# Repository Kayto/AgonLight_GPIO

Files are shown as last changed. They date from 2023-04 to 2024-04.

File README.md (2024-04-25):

# AgonLight_GPIO

## Background
Agon Light is a compact low-cost board that is both a microcomputer and a BASIC-programmed microcontroller. It is intended to be easily hackable and allow interfacing with the outside world. It features 20x GPIO, plus SPI, I2C, UART for serial communication and allows a great opportunity for learning and experimentation.

## Introduction 

This repo is intended to provide some simple add on boards for gpio examples and experiments. Although I am of the 8 bit vintage, I consider myself a novice. I enjoy hardware making as a way to better understand the inner hardware workings and to ultimately improve my coding. All is a work in progress and is open to contributions and ideas, within the stated aims and limitations of this project.

## Aims
* Provide a range of simple IO hardware to aid coding in BBC BASIC.
* To be useful in gaining a general understanding of GPIO usage and real world interfacing.
* Stick to the general GPIOs only.
* Avoid cables and breadboards and try to fit a standardised form factor. In this case a plugable "faceplate" for the exiting gpio port. The board should avoid constraining any existing ports and access.
* Ideally, provide onboard visual feedback to aid learning.
* Avoid additional hardware processing on the add on board. Keeping access to the low level hardware prevents adding more complications when learning. I.e. GALs, additional controller ICs are to be avoided.

## The PCBs

KiCad, Schematics and Gerbers are provided. Renders of the boards are shown in the KiCad directory. Please review before making a commitment. No warranties or support are provided. As of this date PCBs are not yet tested but I will mark as such once done.

#### #1 - The Blinkenlight. - tested working
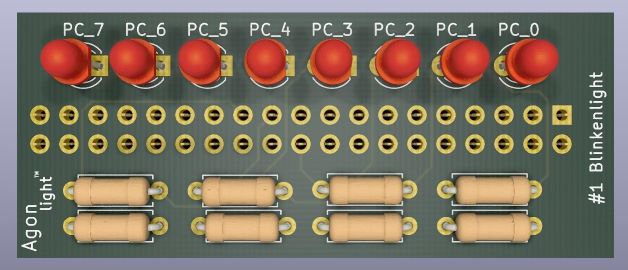
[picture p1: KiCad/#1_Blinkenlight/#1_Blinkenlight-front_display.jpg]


Every 8 bit computer needs blinky lights. Not only do they look like good, they are useful for debugging and understanding what is going on at a bit level.
The Blinkenlight PCB is pretty much the breadboard example from the official documentation but without the fiddly wires. It directly plugs into the GPIO header and provides an easily viewable "faceplate". This presents the form for future boards.

#### #2 - 7 segment display. - tested working
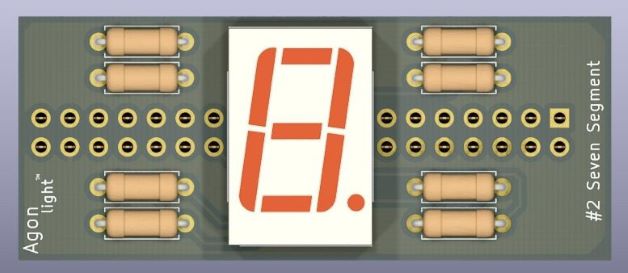
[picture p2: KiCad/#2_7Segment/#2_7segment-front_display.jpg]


This is a single 7 segment display linked to the Port C GPIOs. Allows a simple message display with a delay. Ok its only single digits but something to build on.
A caution on this is that you need a 7 segment display to suit the pin out (they do vary). Review the schematics, Pin 3 and 8 are power.I have provided a solder jumper for setting of common anode and common cathode displays. Note that for common anode the coding assumes a LOW signal for on and HIGH for off.

#### #3 - Double Seven
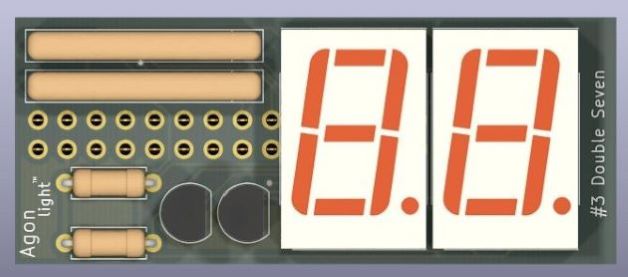
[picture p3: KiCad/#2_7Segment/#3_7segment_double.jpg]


**In progress.**

This is a **double** 7 segment display linked to the Port C GPIOs for data and 2No. Port D GPIOs to do the multiplexing.
To save space resistor networks are used instead of individual resistors.

#### #4 - Moody. - tested working
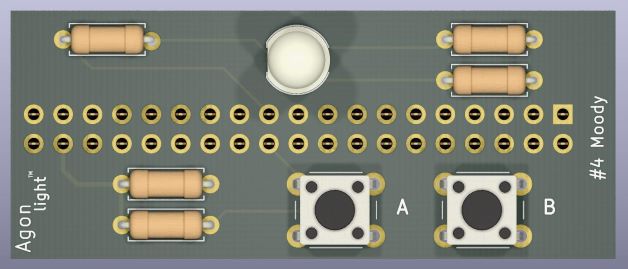
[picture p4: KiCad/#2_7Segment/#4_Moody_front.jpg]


This is an RGB LED linked to the Port C GPIOs, 2No. push buttons are also provided. The two push buttons on PC_3 and PC_4 are to establish some input and mode switching capability. 

## The Code

I have created some code to introduce the boards. As said, coding is not my strength so excuse the code, in some cases its not a great example but enough to get things going and for a challenge to improve.
To view the code add the .BBC files to the SD card and load via BBC BASIC then type LIST.

| Board | Code | Description |
|:---|:---|:-----|
|[#1_Blinkenlight](https://github.com/Kayto/AgonLight_GPIO/tree/main/KiCad/%231_Blinkenlight) | [PortC_blink.bbc](https://github.com/Kayto/AgonLight_GPIO/tree/main/Code) | select individual LEDs, set number of blinks and speed. |
|[#1_Blinkenlight](https://github.com/Kayto/AgonLight_GPIO/tree/main/KiCad/%231_Blinkenlight) | [gpioknight.bbc](https://github.com/Kayto/AgonLight_GPIO/tree/main/Code)| Some blinky patterns. Excuse the code, its a bad example with lots of inefficient duplication to get things done. The **challenge** is open to simplify this, perhaps a data array for the gpio commands and a single procedure for the delay?|
|[#1_Blinkenlight](https://github.com/Kayto/AgonLight_GPIO/tree/main/KiCad/%231_Blinkenlight) | [random8blink.bbc](https://github.com/Kayto/AgonLight_GPIO/tree/main/Code)| An easy change to PortC-Blink, uses the random function and fixed blink speed to just randomly blink the 8 LEDs!|
|[#2_seven_segment](https://github.com/Kayto/AgonLight_GPIO/tree/main/KiCad/%232_7Segment)|  [diceroll.bbc](https://github.com/Kayto/AgonLight_GPIO/tree/main/Code) | A random 1-6 generator for board games, handy. | 
|[#2_seven_segment](https://github.com/Kayto/AgonLight_GPIO/tree/main/KiCad/%232_7Segment)|  [counter.bbc](https://github.com/Kayto/AgonLight_GPIO/tree/main/Code) | A single digit counter, you're welcome. | 
|[#4_Moody](https://github.com/Kayto/AgonLight_GPIO/tree/main/KiCad/%234_Moody)|  [moodyfade.bbc](https://github.com/Kayto/AgonLight_GPIO/tree/main/Code) | An RGB fade using some crude PWM in BBC BASIC. | 
|[#4_Moody](https://github.com/Kayto/AgonLight_GPIO/tree/main/KiCad/%234_Moody)|  [moodybutton.bbc](https://github.com/Kayto/AgonLight_GPIO/tree/main/Code) | The RGB fade but now includes buttons. Button A for on and off. Button B to increase the fade speed.| 

## Disclaimer & Credits

Just a note that I am not in any way affiliated or linked with the Agon project.
I am just an aspiring maker, sharing hobbyist builds.
Thanks to the Agon project and supporters.

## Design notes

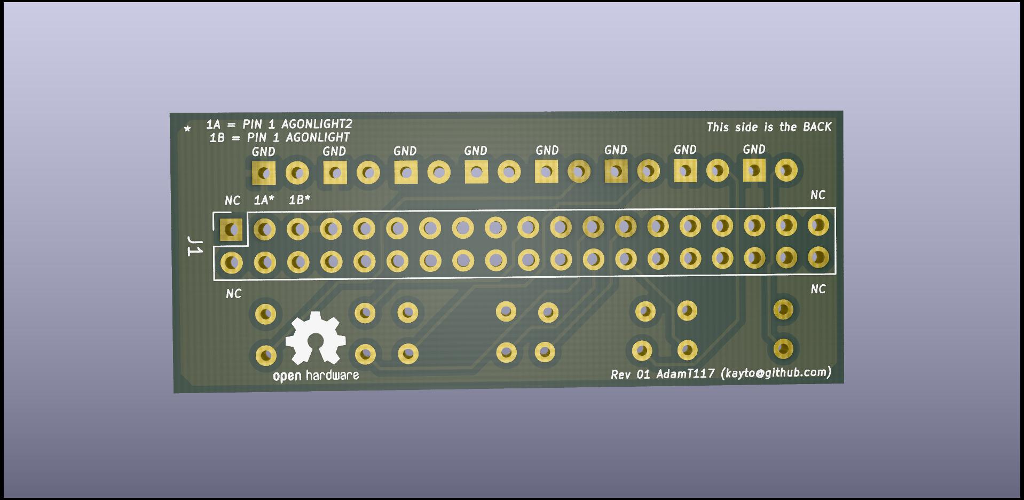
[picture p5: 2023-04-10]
KiCad/#1_Blinkenlight/#1_Blinkenlight-backPCB.jpg

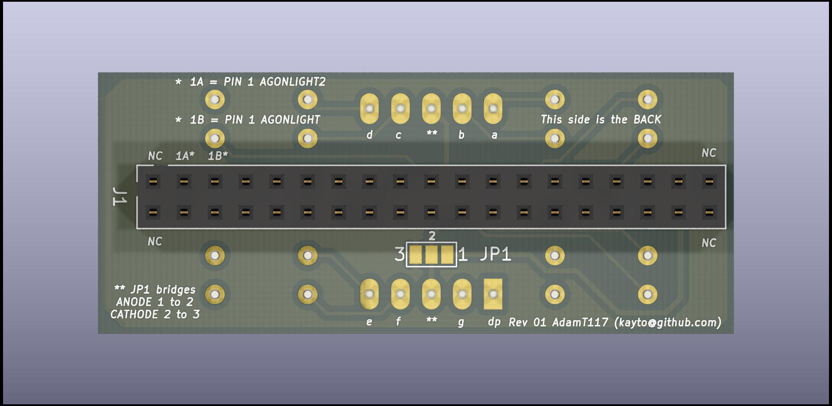
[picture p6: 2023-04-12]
KiCad/#2_7Segment/#2_7segment-back.jpg

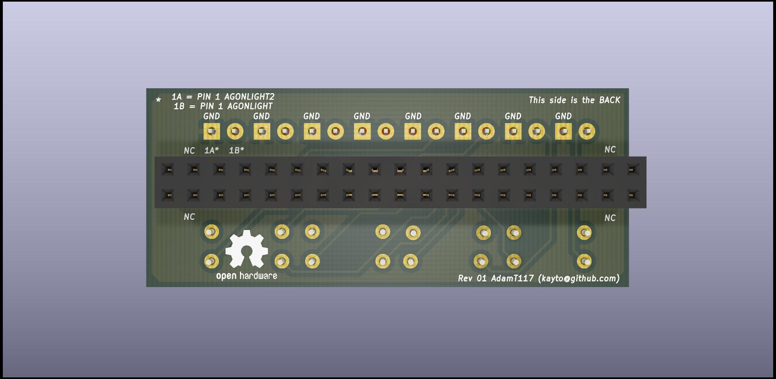
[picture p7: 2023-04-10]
KiCad/#1_Blinkenlight/#1_Blinkenlight-back.jpg

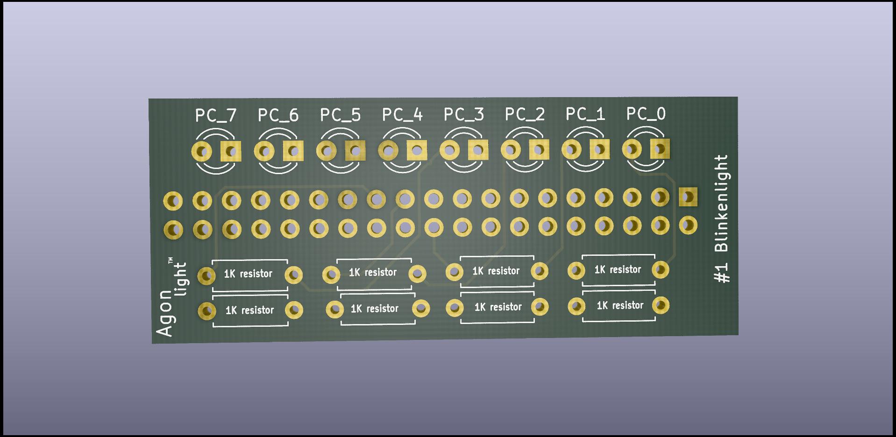
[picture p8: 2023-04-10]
KiCad/#1_Blinkenlight/#1_Blinkenlight-frontPCB.jpg

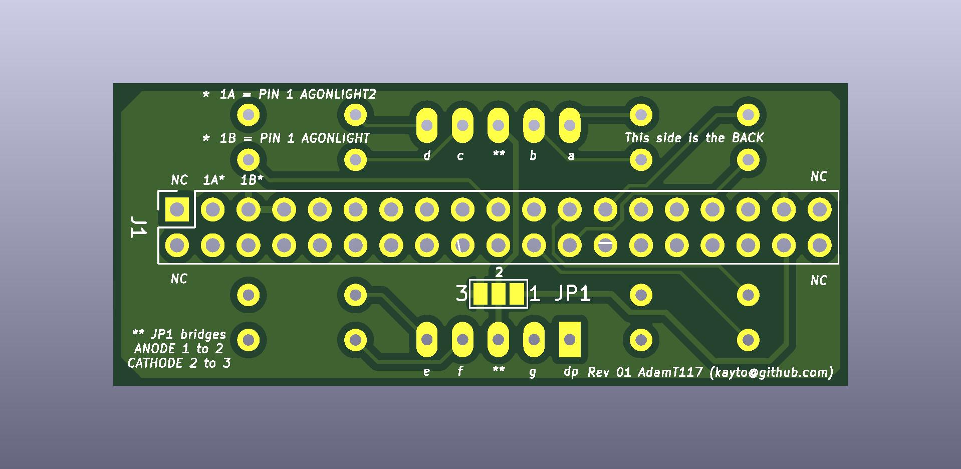
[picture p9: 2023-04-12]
KiCad/#2_7Segment/#2_7segment-back-PCB.jpg

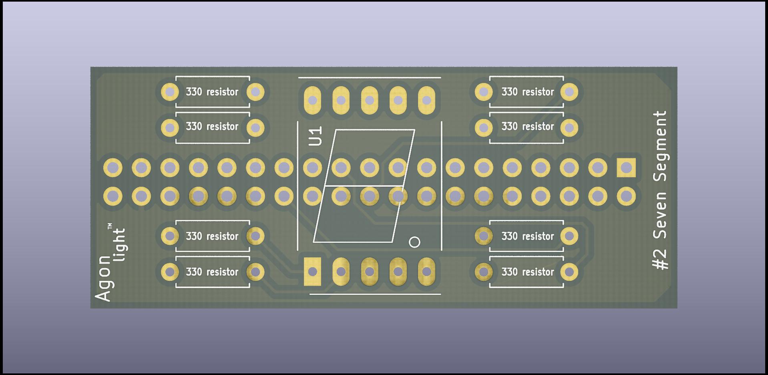
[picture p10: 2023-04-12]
KiCad/#2_7Segment/#2_7segment-front-PCB.jpg

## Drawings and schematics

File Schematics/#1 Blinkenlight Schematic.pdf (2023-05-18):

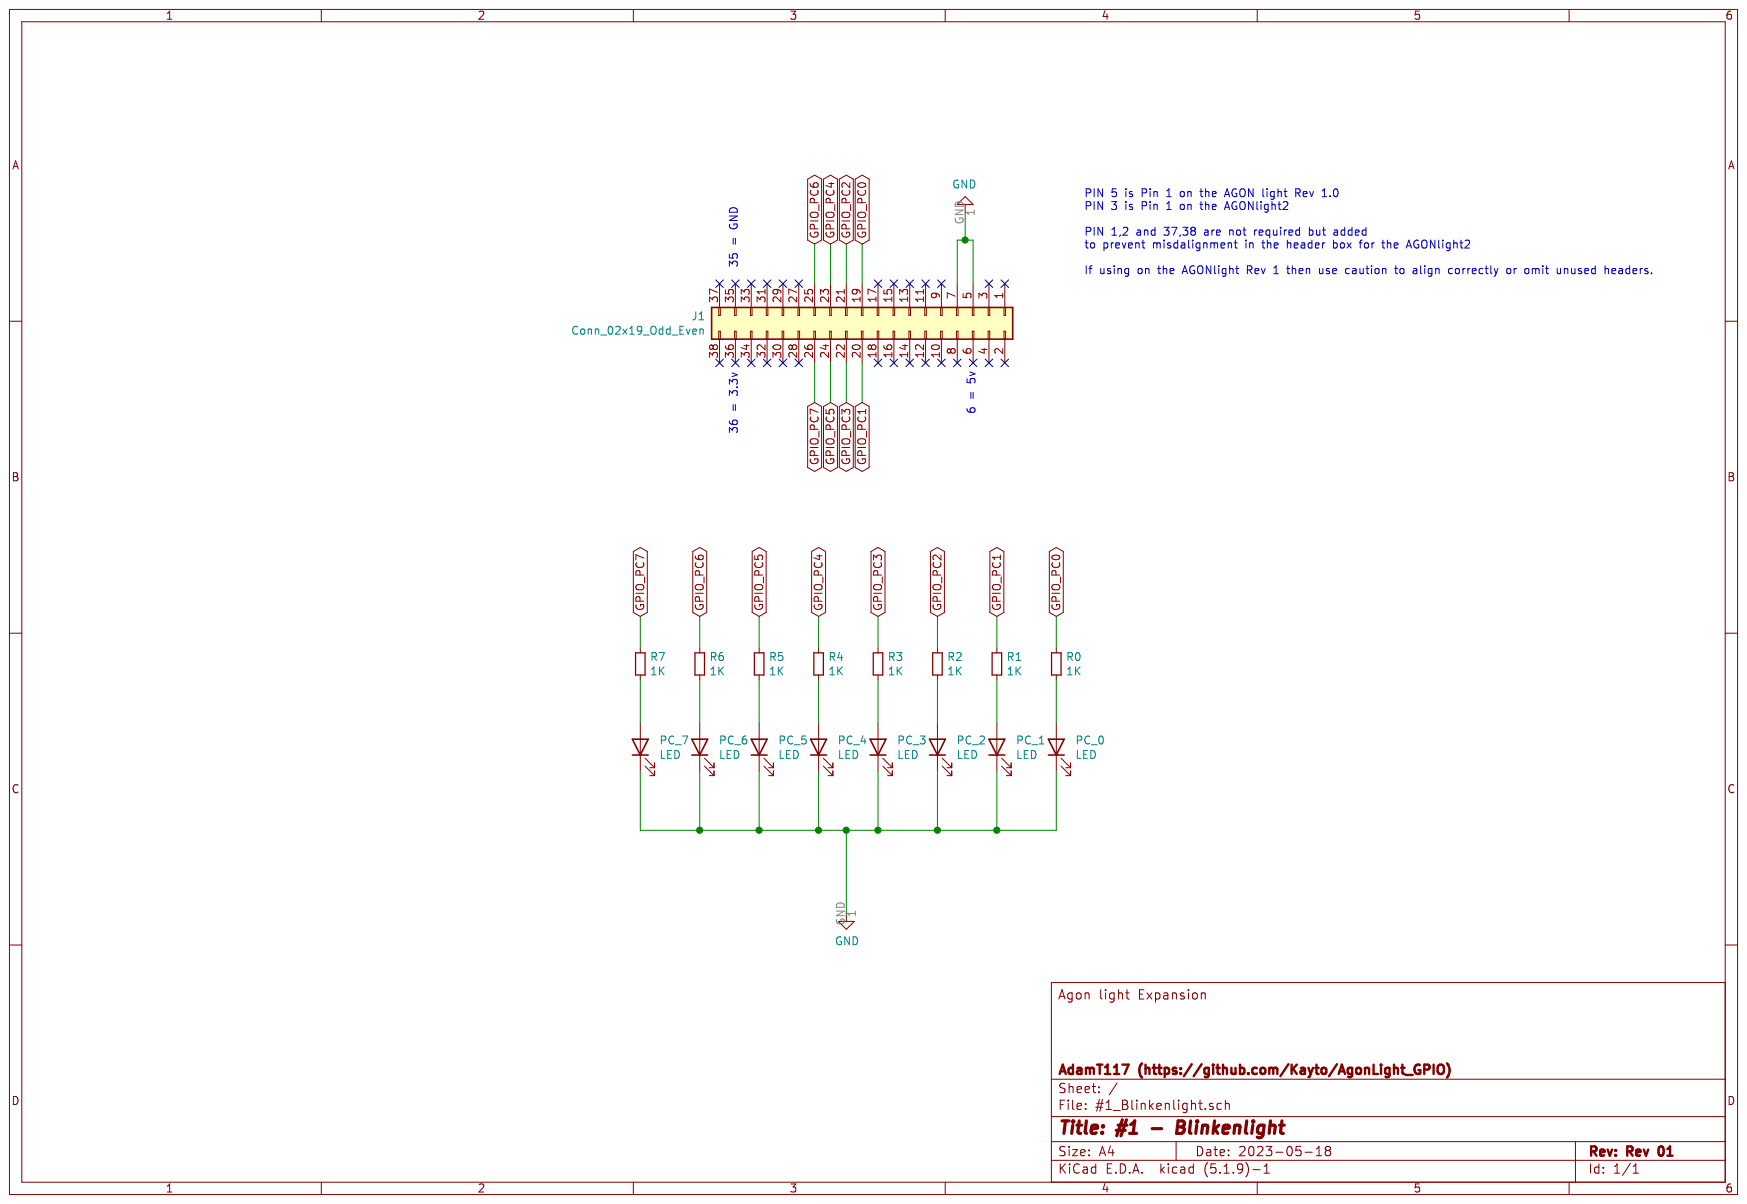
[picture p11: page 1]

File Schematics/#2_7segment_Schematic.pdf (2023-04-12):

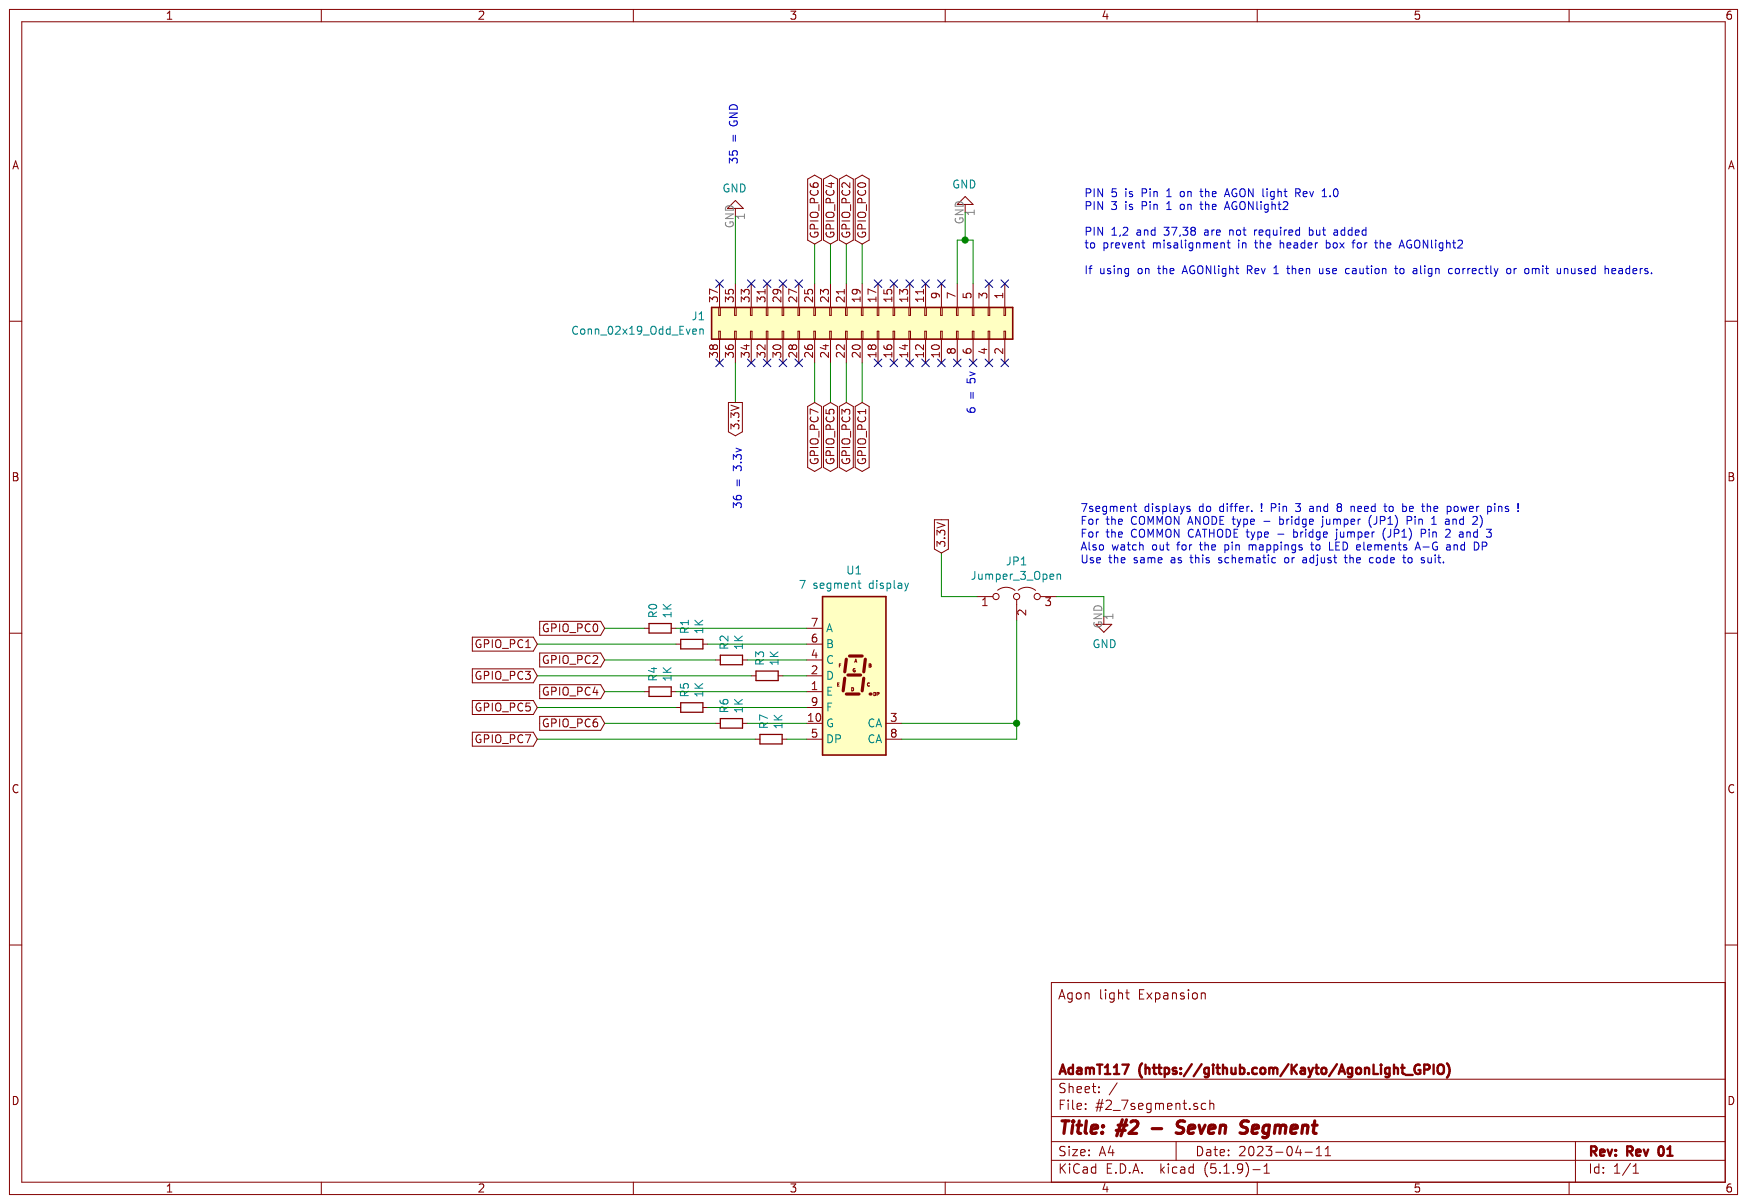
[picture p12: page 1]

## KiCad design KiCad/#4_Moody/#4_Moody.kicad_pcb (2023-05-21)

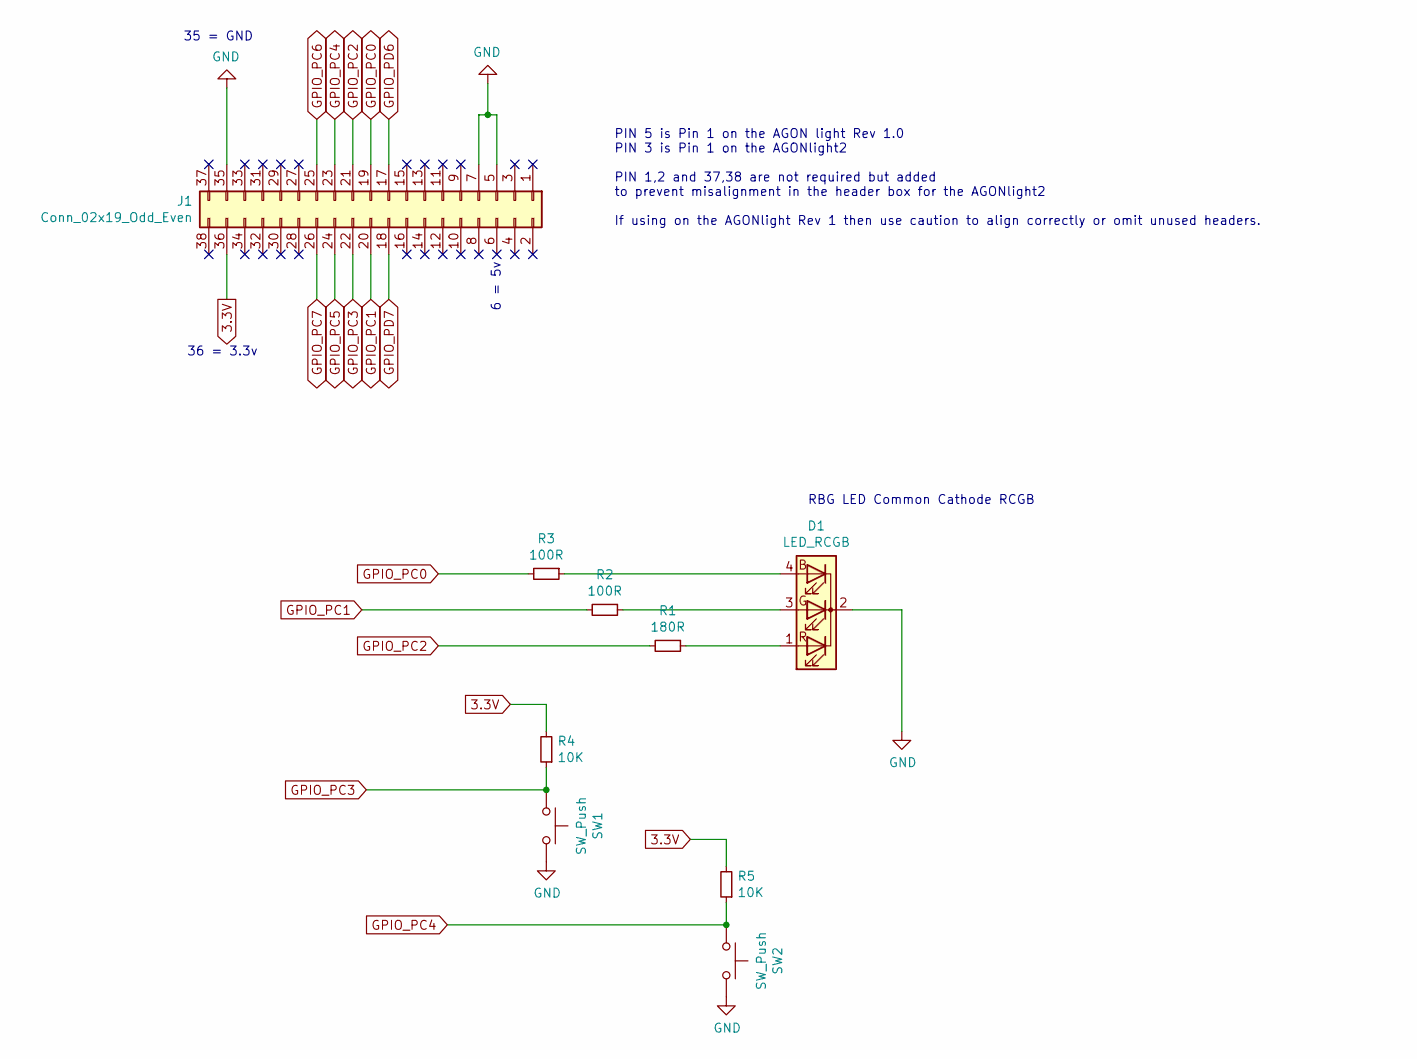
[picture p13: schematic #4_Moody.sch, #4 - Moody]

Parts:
D1: LED_RCGB; LED_D5.0mm-4_RGB
J1: Conn_02x19_Odd_Even; PinSocket_2x19_P2.54mm_Vertical
R1: 180R; R_Axial_DIN0207_L6.3mm_D2.5mm_P7.62mm_Horizontal
R2, R3: 100R; R_Axial_DIN0207_L6.3mm_D2.5mm_P7.62mm_Horizontal
R4, R5: 10K; R_Axial_DIN0207_L6.3mm_D2.5mm_P7.62mm_Horizontal
SW1, SW2: SW_Push; SW_PUSH_6mm_H4.3mm

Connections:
3.3V: J1.36, R4.2, R5.2
GND: D1.2 (K), J1.5, J1.7, J1.35, SW1.2, SW2.2
GPIO_PC0: J1.19, R3.2
GPIO_PC1: J1.20, R2.2
GPIO_PC2: J1.21, R1.2
GPIO_PC3: J1.22, R4.1, SW1.1
GPIO_PC4: J1.23, R5.1, SW2.1
GPIO_PC5: J1.24
GPIO_PC6: J1.25
GPIO_PC7: J1.26
GPIO_PD6: J1.17
GPIO_PD7: J1.18
unnamed: D1.1 (RA), R1.1
unnamed: D1.3 (GA), R2.1
unnamed: D1.4 (BA), R3.1

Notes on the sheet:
PIN 5 is Pin 1 on the AGON light Rev 1.0 PIN 3 is Pin 1 on the AGONlight2 PIN 1,2 and 37,38 are not required but added to prevent misalignment in the header box for the AGONlight2 If using on the AGONlight Rev 1 then use caution to align correctly or omit unused headers.
35 = GND
36 = 3.3v
6 = 5v
RBG LED Common Cathode RCGB

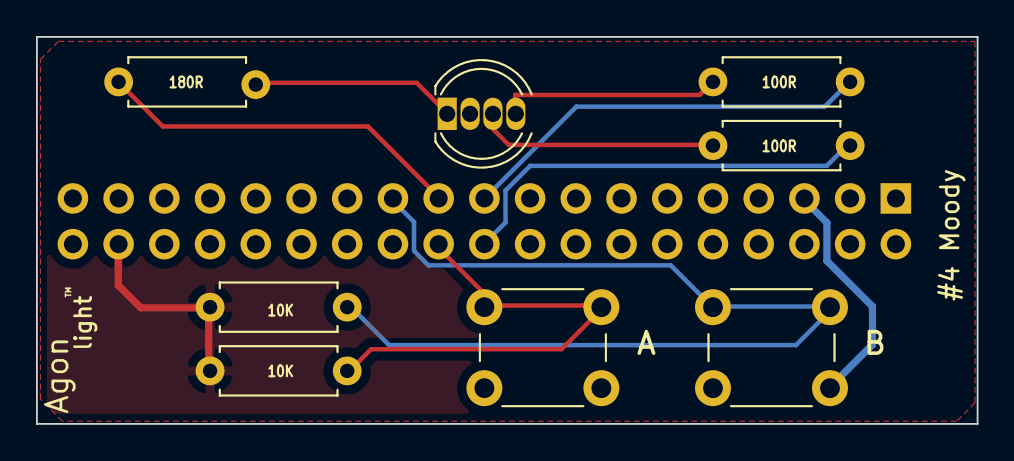
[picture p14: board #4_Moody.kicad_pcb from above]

Board: 2 copper layers, 52.3 x 21.5 mm, 9 parts (1 on the bottom side), 10 nets.

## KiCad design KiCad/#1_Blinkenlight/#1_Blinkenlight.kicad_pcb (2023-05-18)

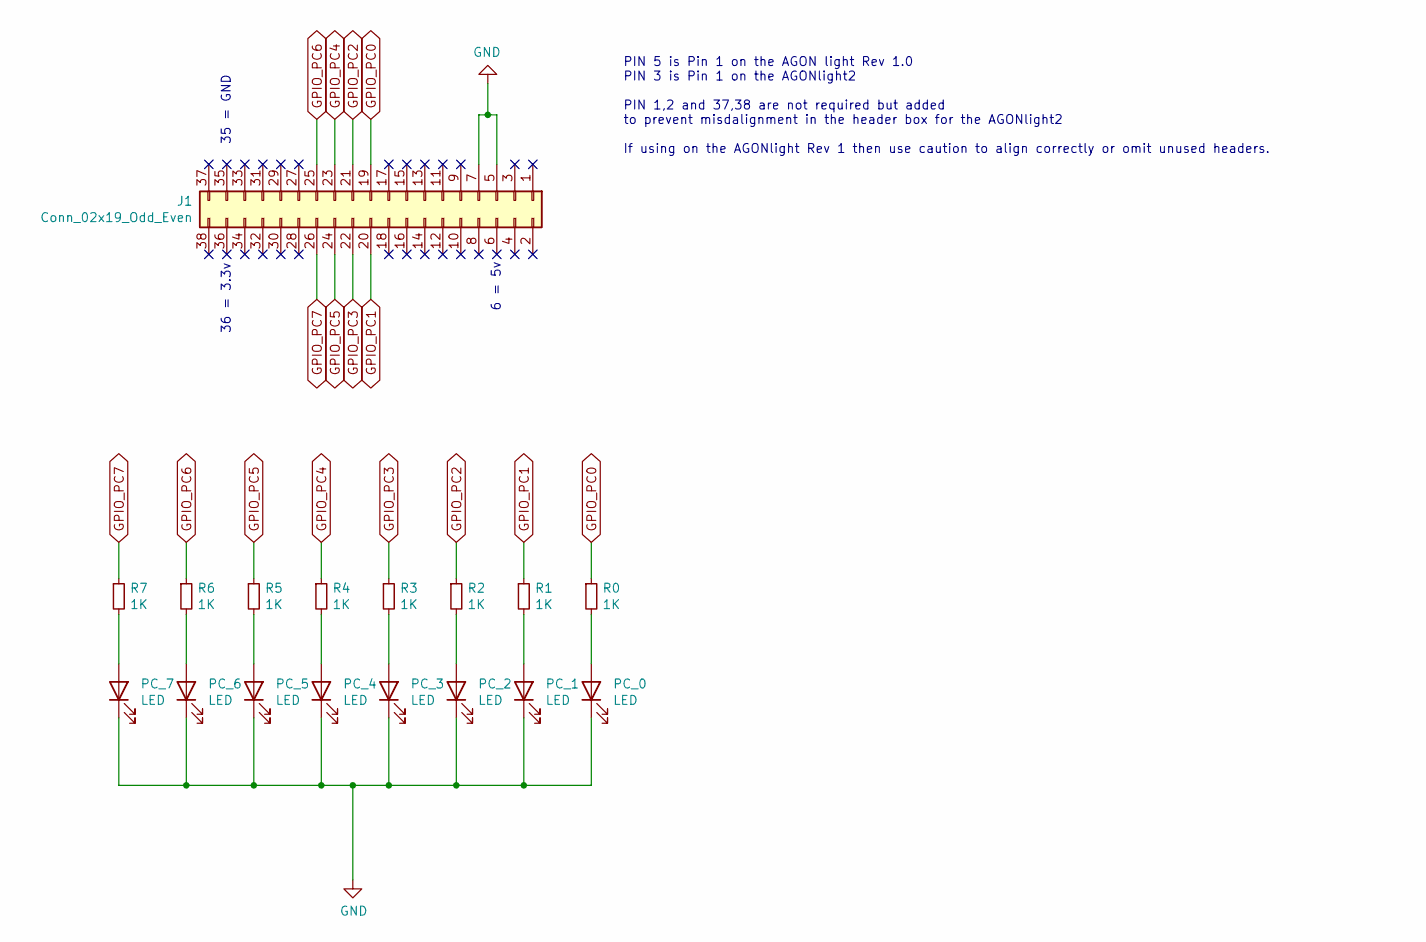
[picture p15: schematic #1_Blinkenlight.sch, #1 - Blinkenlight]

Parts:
J1: Conn_02x19_Odd_Even; PinSocket_2x19_P2.54mm_Vertical
PC_0, PC_1, PC_2, PC_3, PC_4, PC_5, PC_6, PC_7: LED; LED_D3.0mm
R0, R1, R2, R3, R4, R5, R6, R7: 1K; R_Axial_DIN0207_L6.3mm_D2.5mm_P7.62mm_Horizontal

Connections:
GND: J1.5, J1.7, PC_0.1 (K), PC_1.1 (K), PC_2.1 (K), PC_3.1 (K), PC_4.1 (K), PC_5.1 (K), PC_6.1 (K), PC_7.1 (K)
GPIO_PC0: J1.19, R0.1
GPIO_PC1: J1.20, R1.1
GPIO_PC2: J1.21, R2.1
GPIO_PC3: J1.22, R3.1
GPIO_PC4: J1.23, R4.1
GPIO_PC5: J1.24, R5.1
GPIO_PC6: J1.25, R6.1
GPIO_PC7: J1.26, R7.1
unnamed: PC_0.2 (A), R0.2
unnamed: PC_1.2 (A), R1.2
unnamed: PC_2.2 (A), R2.2
unnamed: PC_3.2 (A), R3.2
unnamed: PC_4.2 (A), R4.2
unnamed: PC_5.2 (A), R5.2
unnamed: PC_6.2 (A), R6.2
unnamed: PC_7.2 (A), R7.2

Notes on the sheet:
PIN 5 is Pin 1 on the AGON light Rev 1.0 PIN 3 is Pin 1 on the AGONlight2 PIN 1,2 and 37,38 are not required but added to prevent misdalignment in the header box for the AGONlight2 If using on the AGONlight Rev 1 then use caution to align correctly or omit unused headers.
35 = GND
36 = 3.3v
6 = 5v

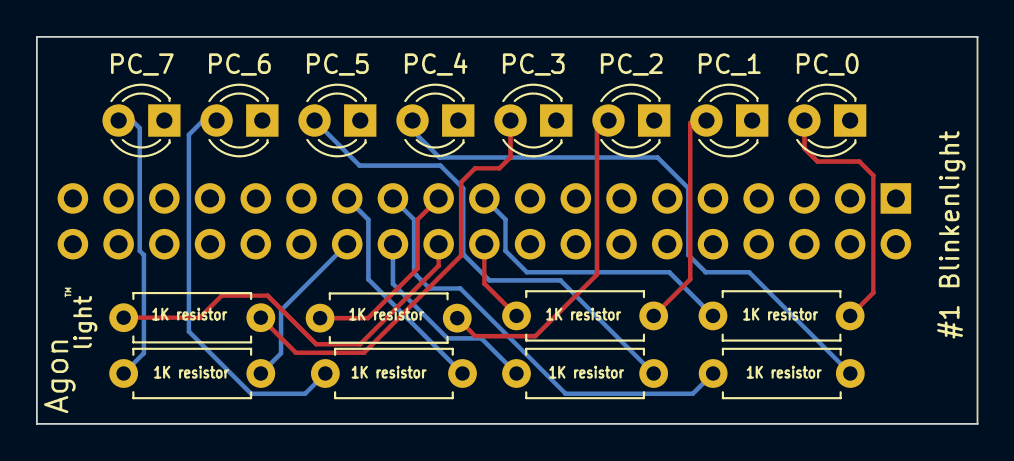
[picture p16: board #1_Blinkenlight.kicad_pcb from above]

Board: 2 copper layers, 52.3 x 21.5 mm, 17 parts (1 on the bottom side), 17 nets.

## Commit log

2023-04-10 KiCad and Gerbers added
    [#1_Blinkenlight-B_Cu.gbl, #1_Blinkenlight-B_Mask.gbs, #1_Blinkenlight-B_Paste.gbp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]
2023-04-12 #2 7 segment PCB added
    [#2_7segment-B_Cu.gbl, #2_7segment-B_Mask.gbs, #2_7segment-B_Paste.gbp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]
2023-04-12 Silk screen
    [#2_7segment-B_Cu.gbl, #2_7segment-B_Mask.gbs, #2_7segment-B_Paste.gbp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]
2023-04-30 #4 Moddy added WIP
    [#4_Moody.kicad_pcb, #4_Moody.sch]
2023-05-18 Blinkenlight schematic correction
    [#1_Blinkenlight-B_Cu.gbl, #1_Blinkenlight-B_Mask.gbs, #1_Blinkenlight-B_Paste.gbp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]
2023-05-21 Schematics moved.
    [#4_Moody.kicad_pcb, #4_Moody.sch]
